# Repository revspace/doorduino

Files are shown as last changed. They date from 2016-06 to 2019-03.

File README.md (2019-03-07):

# Doorduino

## Configuration

Create a configuration file for every door, in which 'dev' points to the
serial device of the associated Arduino. The configuration file has to be valid
Perl syntax, and return a list of key/value pairs.

    echo "dev => '/dev/ttyUSB0'" > /home/pi/frontdoor.conf.pl
    echo "dev => '/dev/ttyUSB1'" > /home/pi/backdoor.conf.pl

Add keys to files in `ibuttons.acl.d`, and optionally add executable scripts to
`granted.d` and `denied.d`.

An example configuration file:

    dev => "/dev/ttyUSB0",
    ircname => "main door",
    allow_insecure => 1,

Valid configuration entries are:

| Key | Default value | Description
| --- | --- | ---
| `dev` | (mandatory) | Arduino serial device
| `ircname` | (config name) | Display name
| `acldir` | `ibuttons.acl.d` | Directory in which to look for .acl files
| `allow_insecure` | 0 | Set to a true value (such as 1) to enable ID-only access 

## ID-only support (insecure mode)

By default, only SHA1 secure iButtons (DS1961S) are supported. Some
organizations will have insecure ID-only iButtons (like the DS1990A), and want
to upgrade. In other cases, leaking the shared secret would be worse than
allowing access to the wrong people, and you may want to authenticate against
the ID without having the secret available on the controlling Linux computer
(e.g. Raspberry Pi) if you fear the physical controlling device might get
stolen or broken into.

In these cases, set `allow_insecure => 1`. Note that if there's a secret in the
.acl file, it will still be verified. To disable SHA1 verification of the
shared secret, list the ID without a colon or a secret.

## Starting manually, in the foreground

    ./doorduino.pl frontdoor  # or another config file

## Starting automatically using the systemd unit

    cp doorduino@.service /etc/systemd/system

    systemctl enable doorduino@frontdoor
    systemctl enable doorduino@backdoor

    systemctl status doorduino@frontdoor

## Starting automatically with cron

See `doc/crontab.example` and `scripts/restartloop.sh`

## See also

https://revspace.nl/Doorduino

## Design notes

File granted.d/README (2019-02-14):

Add scripts to this directory, make them executable. They will be executed by
"run-parts", so read its documentation for learning which filenames are
acceptable. The combined scripts must finish within 5 seconds or they will be
killed.

Note that this is probably the place where you'll introduce security bugs that
may result in unauthorized access to your building, or denial of service bugs
so that eventually nobody can enter anymore. Be careful.

The following environment variables are available:

    DOORDUINO_IRCNAME       Name of the lock
    DOORDUINO_ID            ID of the user or "UNKNOWN"
    DOORDUINO_NAME          Name of the user or "Unknown"
    DOORDUINO_REASON        What led to granting or denying access

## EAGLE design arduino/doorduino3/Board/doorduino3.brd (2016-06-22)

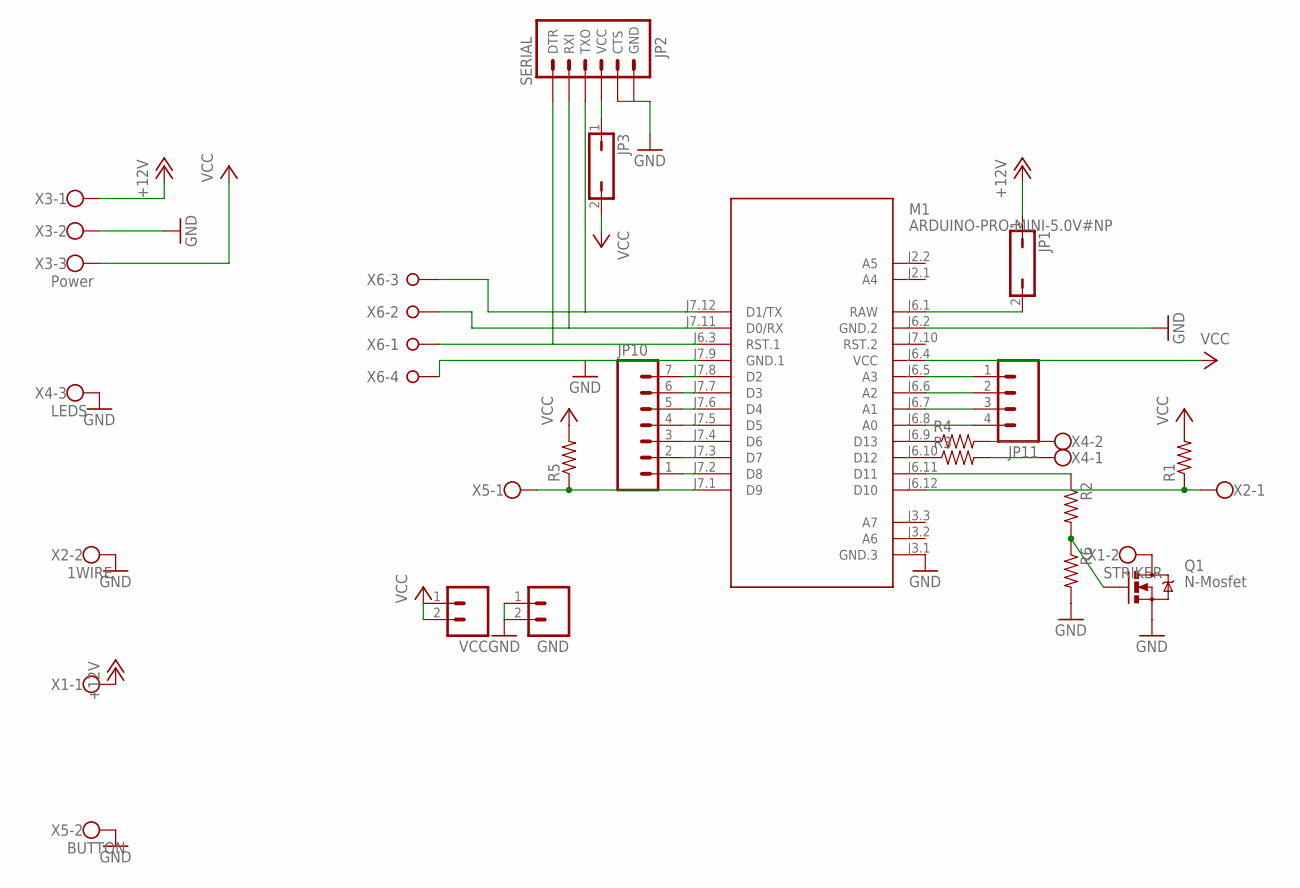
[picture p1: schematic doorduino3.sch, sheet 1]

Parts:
GND: M021X02_NO_SILK; 1X02_NO_SILK
JP1, JP3: JP1Q; JP1
JP2: SERIAL; 1X06_LONGPADS
JP10: M07; 1X07
JP11: M04NO_SILK_ALL_ROUND; 1X04_NO_SILK_ALL_ROUND
M1: ARDUINO-PRO-MINI-5.0V#NP; ARDUINO-PRO-MINI#NP
Q1: N-Mosfet; TO220V
R1, R2, R3, R4, R5, R6: RESISTOR0805-RES; 0805
VCC: M021X02_NO_SILK; 1X02_NO_SILK
X1: STRIKER; W237-102
X2: 1WIRE; W237-102
X3: Power; W237-103
X4: LEDS; W237-103
X5: BUTTON; W237-102
X6: W237-04P; W237-4P

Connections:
+12V: JP1.1, X1.1, X3.1
GND: GND.1, GND.2, JP2.5 (CTS), JP2.6 (GND), M1.J3.1 (GND.3), M1.J6.2 (GND.2), M1.J7.9 (GND.1), Q1.3 (S), R6.2, X2.2, X3.2, X4.3, X5.2, X6.4
unnamed: JP1.2, M1.J6.1 (RAW)
unnamed: M1.J6.12 (D10), R1.1, X2.1
unnamed: M1.J6.11 (D11), R2.1
unnamed: Q1.1 (G), R2.2, R6.1
unnamed: Q1.2 (D), X1.2
unnamed: M1.J6.10 (D12), R3.1
unnamed: M1.J6.9 (D13), R4.1
unnamed: R3.2, X4.1
unnamed: R4.2, X4.2
unnamed: M1.J7.1 (D9), R5.1, X5.1
unnamed: JP2.3 (TXO), M1.J7.12 (D1/TX), X6.3
unnamed: JP2.2 (RXI), M1.J7.11 (D0/RX), X6.2
unnamed: JP2.4 (VCC), JP3.1
unnamed: JP2.1 (DTR), M1.J6.3 (RST.1), X6.1
unnamed: JP10.1, M1.J7.2 (D8)
unnamed: JP10.2, M1.J7.3 (D7)
unnamed: JP10.3, M1.J7.4 (D6)
unnamed: JP10.4, M1.J7.5 (D5)
unnamed: JP10.5, M1.J7.6 (D4)
unnamed: JP10.6, M1.J7.7 (D3)
unnamed: JP10.7, M1.J7.8 (D2)
unnamed: JP11.1, M1.J6.5 (A3)
unnamed: JP11.2, M1.J6.6 (A2)
unnamed: JP11.3, M1.J6.7 (A1)
unnamed: JP11.4, M1.J6.8 (A0)
VCC: JP3.2, M1.J6.4 (VCC), R1.2, R5.2, VCC.1, VCC.2, X3.3

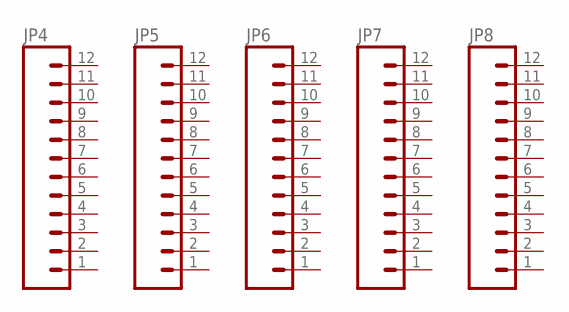
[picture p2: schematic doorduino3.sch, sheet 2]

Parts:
JP4, JP5, JP6, JP7, JP8: M12NO_SILK; 1X12_NO_SILK

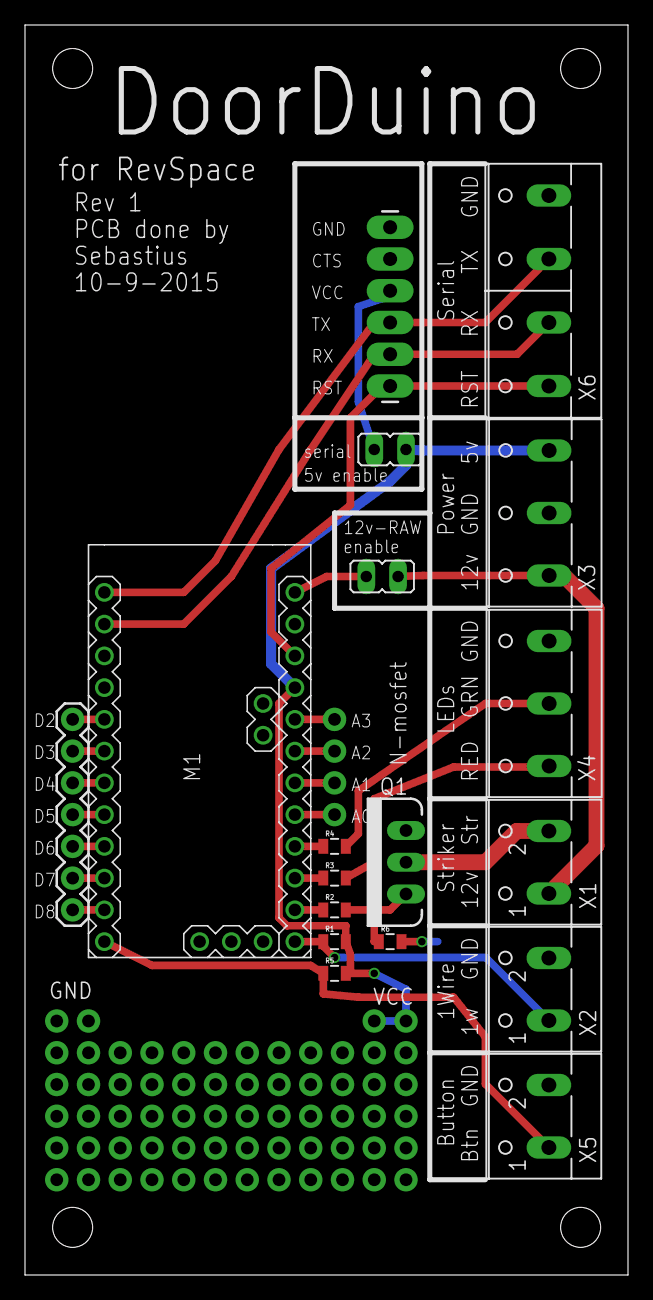
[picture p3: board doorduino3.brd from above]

Board: 2 copper layers, 48.2 x 100.0 mm, 26 parts (0 on the bottom side), 28 nets.

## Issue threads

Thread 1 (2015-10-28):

Uitlijning en fonts boardfile

sebastius, 2015-10-28:
De lettertjes van de kleine componenten zijn niet te lezen na bedrukking door DirtyPCBs. Tevens is de uitlijning van de twee jumperbloks nét niet mooi.

sebastius, 2016-06-22:
Gek genoeg zijn de pads van de 0805 weerstanden bij de tweede bestelling een haartje kleiner uitgevallen dan bij de eerste bestelling. Toch maar de pads ook iets vergroten. En dan meteen die opdruk ook!

sebastius, 2016-06-22:
Pads uiteindelijk niet veranderd. Wel wat gedaan aan de opdruk, die zou nu mooier moeten lukken (ook de weerstanden, heb de waardes verstopt onder de arduino).

Verder een groundplane toegevoegd aan de bovenzijde.

Closed 2016-06-22.

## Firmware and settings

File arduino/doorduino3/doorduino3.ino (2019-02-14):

#include <OneWire.h>
#include "ds1961.h"
#include "hexutil.c"
/*

  5V -----\/\/\-----+
          R=2k      |
  10 ---------------+------------o   o-----1wire----+
                                                    |
                            +----o   o-----door     |
                            |              opener   |
                         |--+                |      |
  11 -----\/\/\---+------| NPN mosfet        |      |
          R=150   |      |--+ (e.g. irf540)  |      |
                  /         |              +12V     |
                  \         |                       |
                  / R=10k   |                       |
                  \         |                       |
                  |         |                       |
 GND -------------+---------+----o   o--------------+
                                                    |
                                                    |
  12 -----\/\/\------------------o   o------>|------+
          R=220                             red     |
                                                    |
  13 -----\/\/\------------------o   o------>|------+
          R=220                            green    |
                                                    |
  Optional:                                  |      |
                                           -----    |
   9 ----------------------------o   o-----o   o----+
                    |
  5V -----\/\/\-----+
          R=1k

*/


#define PIN_LED_GREEN 13
#define PIN_LED_RED   12
#define PIN_UNLOCK    11
#define PIN_1WIRE     10
#define PIN_BUTTON     9

#define OFF    0
#define GREEN  1
#define RED    2
#define YELLOW (GREEN | RED)

OneWire ds(PIN_1WIRE);
DS1961  sha(&ds);

const int delay_access   =  6000;
const int delay_noaccess = 10000;

byte id[8];

void led (byte color) {
  digitalWrite(PIN_LED_GREEN, color & GREEN);
  digitalWrite(PIN_LED_RED,   color & RED);
}

void setup () {
  Serial.begin(115200);
  Serial.println("RESET");
  pinMode(PIN_LED_GREEN, OUTPUT);
  pinMode(PIN_LED_RED,   OUTPUT);
  pinMode(PIN_UNLOCK,    OUTPUT);
  pinMode(PIN_BUTTON,    INPUT);
  digitalWrite(PIN_BUTTON, HIGH);

  led(YELLOW);
}

static bool connected = false;
static unsigned long error_flash;

void error () {
  connected = false;
  error_flash = millis() + 200;
}

void loop () {
  char challenge[3];
  
  static unsigned long keepalive = 0;

  if (! (connected && ds.reset())) {  // read ds.reset() as ds.still_connected()
    connected = false;
    ds.reset_search();
    if (ds.search(id)) {
      if (OneWire::crc8(id, 7) != id[7]) return;
      connected = true;
      led(OFF);
      Serial.print("<");
      for (byte i = 0; i < 8; i++) {
        if (id[i] < 16) Serial.print("0");
        Serial.print(id[i], HEX);
      }
      Serial.println(">");
    }
  }
  
  int button = 0;
  for (; button < 10 && !digitalRead(PIN_BUTTON); button++) delay(1);
  if (button >= 10) {
    Serial.println("<BUTTON>");
  }

  if (!connected && error_flash && error_flash < millis()) {
    error_flash = 0;
    for (int i = 0; i < 5; i++) {
      led(OFF);
      delay(50);
      led(YELLOW);
      delay(25);
    }
  }

  if (connected) {
    led(OFF);
  } else {
    unsigned int m = millis() % 3000;
    bool have_comm = (keepalive && millis() - 5000 < keepalive);
    led( 
      ((m > 2600 && m <= 2700) || (m > 2900))
      ? (have_comm ? OFF : RED)
      : (have_comm ? YELLOW : OFF)
    );
  }

  while (Serial.available()) {
    char c = Serial.read();
    
    if (c == 'A') {
      // XXX Wat als een challenge ooit "A" bevat?
      Serial.println("ACCESS");
      led(GREEN);
      digitalWrite(PIN_UNLOCK, HIGH);
      delay(delay_access);
      digitalWrite(PIN_UNLOCK, LOW);
      led(YELLOW);
      keepalive = millis();
      error_flash = 0;
    }
    else if (c == 'N') {
      Serial.println("NO ACCESS");
      led(RED);
      delay(delay_noaccess);
      led(YELLOW);
      keepalive = millis();
      error_flash = 0;
    } else if (c == 'C') {
      led(OFF);

      unsigned char page[1];

      if (Serial.readBytes(page, 1) != 1) return;
      if (Serial.readBytes(challenge, 3) != 3) return;

      if (! ibutton_challenge(page[0], (byte*) challenge)) {
        Serial.println("CHALLENGE ERROR");
        if (!ds.reset()) error();
        return;
      }
    } else if (c == 'X') {
      led(OFF);

      unsigned char page[1];
      char newdata[8];
      char mac[20];
      unsigned char offset[1];
      if (Serial.readBytes(page, 1) != 1) return;
      if (Serial.readBytes(challenge, 3) != 3) return;
      if (Serial.readBytes(offset, 1) != 1) return;
      if (Serial.readBytes(newdata, 8) != 8) return;
      if (Serial.readBytes(mac, 20) != 20) return;

      if (! sha.WriteData(NULL, page[0] * 32 + offset[0], (uint8_t*) newdata, (uint8_t*) mac)) {
        Serial.println("EEPROM WRITE ERROR");
        error();
        return;
      }
      if (! ibutton_challenge(page[0], (byte*) challenge)) {
        Serial.println("EXTENDED CHALLENGE ERROR");
        error();
        return;
      }
    } else if (c == 'K') {
      keepalive = millis();
      Serial.println("<K>");
    }
  }
  
  //while (Serial.available()) Serial.read();
}

bool ibutton_challenge(byte page, byte* challenge) {
  uint8_t data[32];
  uint8_t mac[20];
  
  if (! sha.ReadAuthWithChallenge(NULL, page * 32, challenge, data, mac)) {
    return false;
  }
  Serial.print("<");
  hexdump(data, 32);
  Serial.print(" ");
  hexdump(mac, 20);
  Serial.println(">");  
  return true;
}

void hexdump(byte* string, int size) {
  for (int i = 0; i < size; i++) {
    Serial.print(string[i] >> 4, HEX);
    Serial.print(string[i] & 0xF, HEX);
  }
}

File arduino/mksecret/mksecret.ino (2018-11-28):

#include "Entropy.h"
#include "OneWire.h"
#include "ds1961.h"
#include "hexutil.c"

/*

  5V -----\/\/\-----+
          R=4k7     |
  10 ---------------+------------o   o-----1wire----+
                                                    |
                                                    |
  12 -----\/\/\------------------o   o------>|------+
          R=220                             red     |
                                                    |
  13 -----\/\/\------------------o   o------>|------+
          R=220                            green    |
                                                    |
 GND ----------------------------o   o--------------+

*/


#define PIN_LED_GREEN 13
#define PIN_LED_RED   12
#define PIN_1WIRE     10

#define OFF    0
#define GREEN  1
#define RED    2
#define YELLOW (GREEN | RED)

OneWire ds(PIN_1WIRE);
DS1961  sha(&ds);

byte addr[8];

void led (byte color) {
  digitalWrite(PIN_LED_GREEN, color & GREEN);
  digitalWrite(PIN_LED_RED,   color & RED);
}

void setup () {
  Serial.begin(9600);
  Serial.println("RESET");
  pinMode(PIN_LED_GREEN, OUTPUT);
  pinMode(PIN_LED_RED,   OUTPUT);
  Entropy.initialize();
}

void loop () {
  
  byte secret[8];
  int i;
  
  for (i = 0; i < 8; i++) {
    secret[i] = Entropy.random(256);
  }
  
  while (1) { /* yo dawg */
  
    ds.reset_search();
    if (ds.search(addr)) {
      if (OneWire::crc8(addr, 7) != addr[7]) return;
      delay(100);
      hexdump(addr, 8);
      Serial.print(":");
  
      if (!sha.WriteSecret(addr, secret)) {
        Serial.println("ERROR");
        led(RED);
      } else {
        hexdump(secret, 8);
        Serial.println("");
        led(GREEN);
      }
      delay(5000);
      
      break;
    }
    
    led( millis() % 150 > 120 ? OFF : RED
    );
  }

}

void hexdump(byte* string, int size) {
  for (int i = 0; i < size; i++) {
    Serial.print(string[i] >> 4, HEX);
    Serial.print(string[i] & 0xF, HEX);
  }
}

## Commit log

2012-10-31 Eerste commit, zoals het nu in productie draait.
2012-11-02 Blijkbaar sloop je een arduino als je die diode niet gebruikt :)
2013-08-17 Workaround for unexpected calculation in Perl/ARM.
2015-06-25 Move libraries to lib folder for inotool/arduino compatibility
2015-10-01 Resistors, mosfet
2015-10-28 Boardlayouts DD3 rev 1
    Boardfiles in Cadsoft Eagle. Deze versie is degene die we nu in huis
    hebben.
    [doorduino3.brd, doorduino3.sch]
2016-06-02 Update push.sh with current version
    Now includes a hack to add someone to a list that isn't
    used with the front door (10.42.42.42).
2016-06-03 Rename variable; led off during ibutton comms
    The variable name 'addr' became confusing because the EEPROM also
    uses addresses. The DS1961S datasheet calls them "registration
    numbers", the DS1991 datasheet uses "64-bit ROM code". But 'id'
    is much shorter :-)
2016-06-22 Debounce button
2016-06-22 Rev 1.1, mainly cosmetic
    Ground plane on both sides
    Better text size/alignment
    Arduino pinout simplified (less holes!)
    Minor cosmetics
    [doorduino3.brd]
2016-06-22 Folder rename
    DD2 -> DD3
    [doorduino3.brd, doorduino3.sch]
2016-06-26 Script for flashing to ALL connected arduinos
2016-07-11 Spul weg dat niet meer op de space is.
2019-02-14 Reorganize, move arduino stuff to arduino/
2019-02-14 Update color, remove duplicate files
    [doorduino3.brd, doorduino3.sch]

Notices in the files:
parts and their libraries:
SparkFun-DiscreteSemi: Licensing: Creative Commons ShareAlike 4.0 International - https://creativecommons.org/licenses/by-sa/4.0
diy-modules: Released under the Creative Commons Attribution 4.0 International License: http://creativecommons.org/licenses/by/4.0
